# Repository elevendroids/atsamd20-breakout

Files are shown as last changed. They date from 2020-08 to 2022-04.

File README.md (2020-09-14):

# ATSAMD2x (SAM D2x) Breakout Board (Rev. A)

Small breakout board designed for the [SAM D20](http://ww1.microchip.com/downloads/en/DeviceDoc/SAM_D20_%20Family_Datasheet_DS60001504C.pdf) and [SAM D21](http://ww1.microchip.com/downloads/en/DeviceDoc/SAM_D21_DA1_Family_DataSheet_DS40001882F.pdf) ARM Cortex-M0+ microcontrollers from Microchip

## Features

- minimal subset of components, no power regulation etc.
- optional external main and real-time crystals - if not used, their GPIO pins can be connected to the user header by soldering relevant 0R resistors (see schematic)
- one buffered user LED, connected to the header - no reserved GPIO
- reset button
- standard 0.05" pitch SWD programming header, SWD signals also present on the pin headers

Designed in KiCad 5.1.6

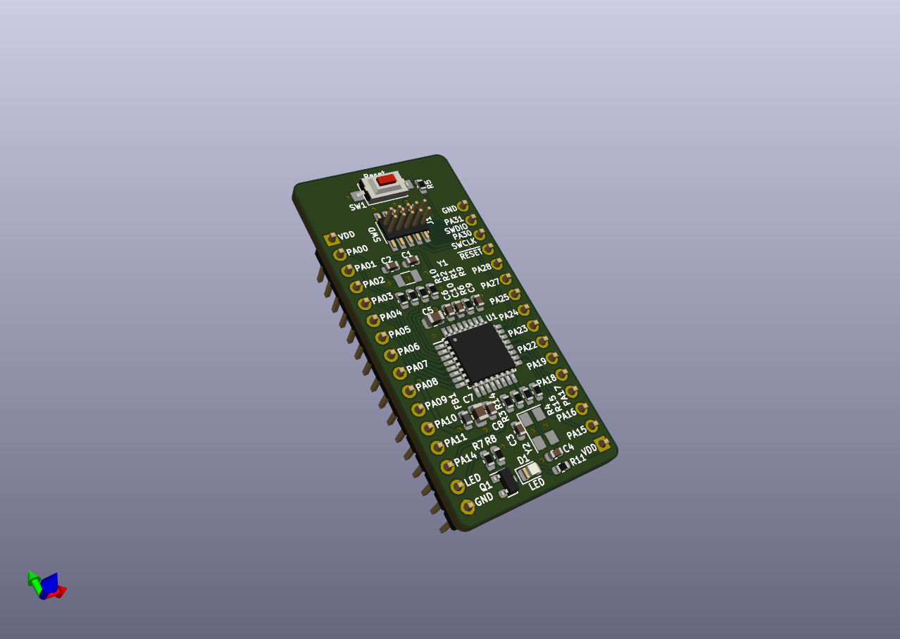
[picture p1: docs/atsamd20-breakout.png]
PCB Render


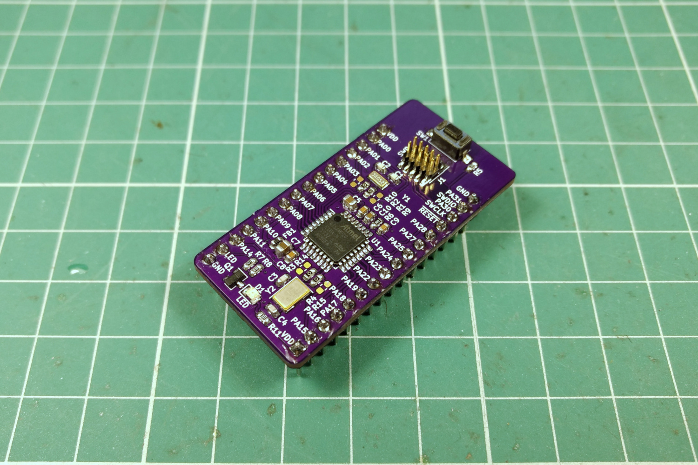
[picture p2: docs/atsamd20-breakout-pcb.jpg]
Prototype


Schematic: [PDF](docs/atsamd20-breakout.pdf)

License: [CC BY-SA 4.0](https://creativecommons.org/licenses/by-sa/4.0/)

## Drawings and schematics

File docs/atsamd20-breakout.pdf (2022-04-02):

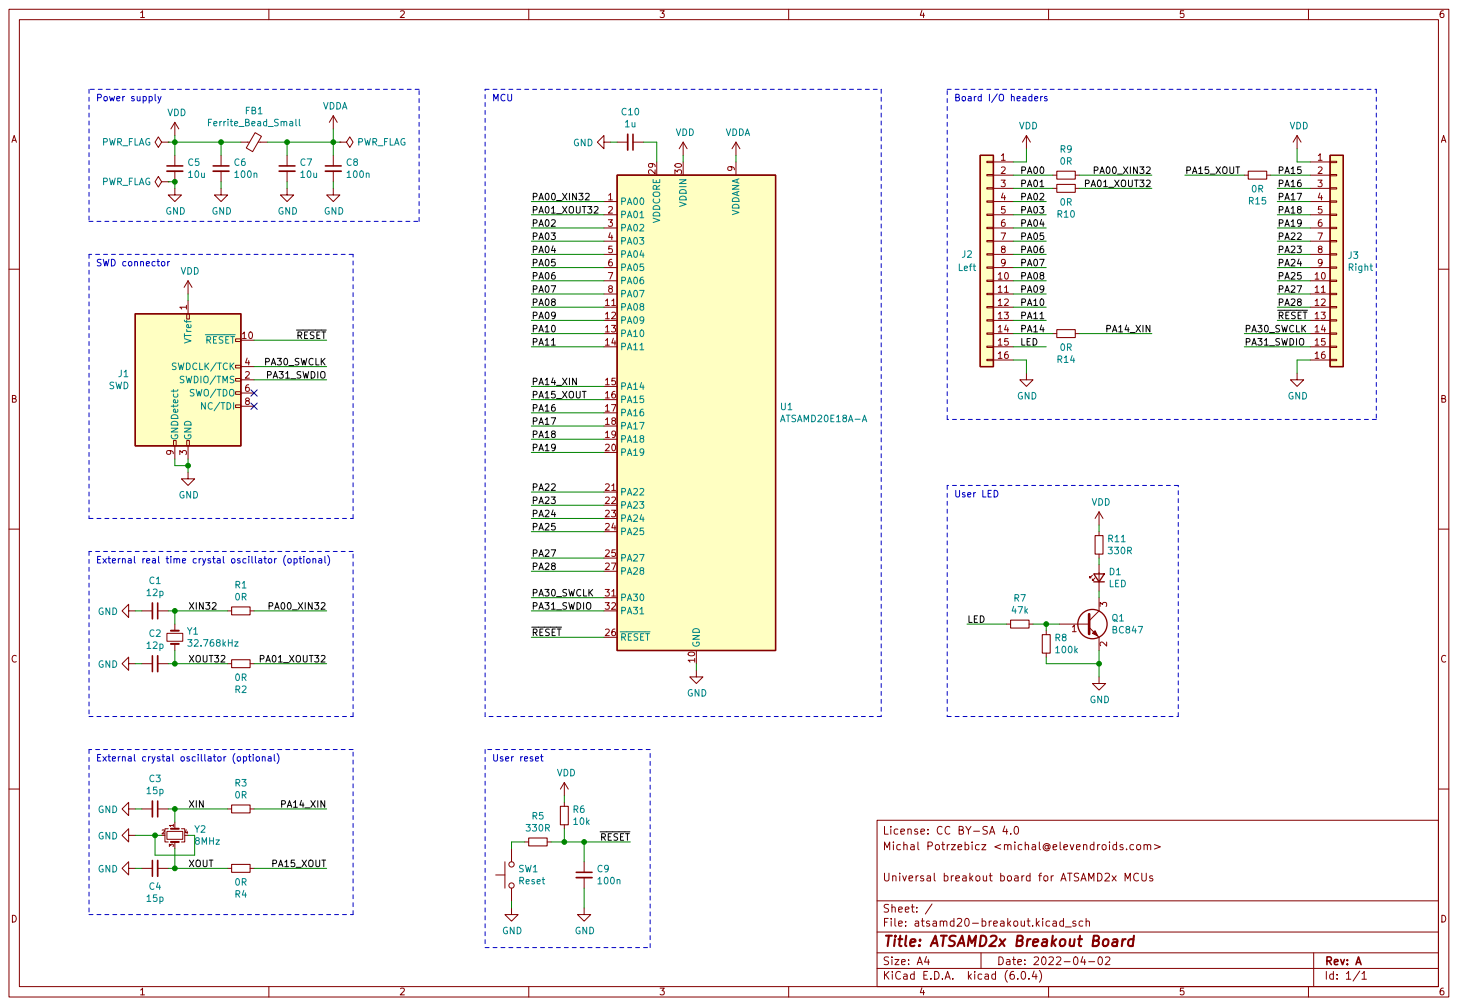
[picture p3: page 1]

3 SWDCLK/TCK 4 SWO/TDO 6 NC/TDI 8 GNDDetect 9

External real time crystal oscillator (optional)
8MHz C1

License: CC BY-SA 4.0
File: atsamd20-breakout.kicad_sch Sheet: / Universal breakout board for ATSAMD2x MCUs Michal Potrzebicz <michal@elevendroids.com>

Id: 1/1 Title: ATSAMD2x Breakout Board

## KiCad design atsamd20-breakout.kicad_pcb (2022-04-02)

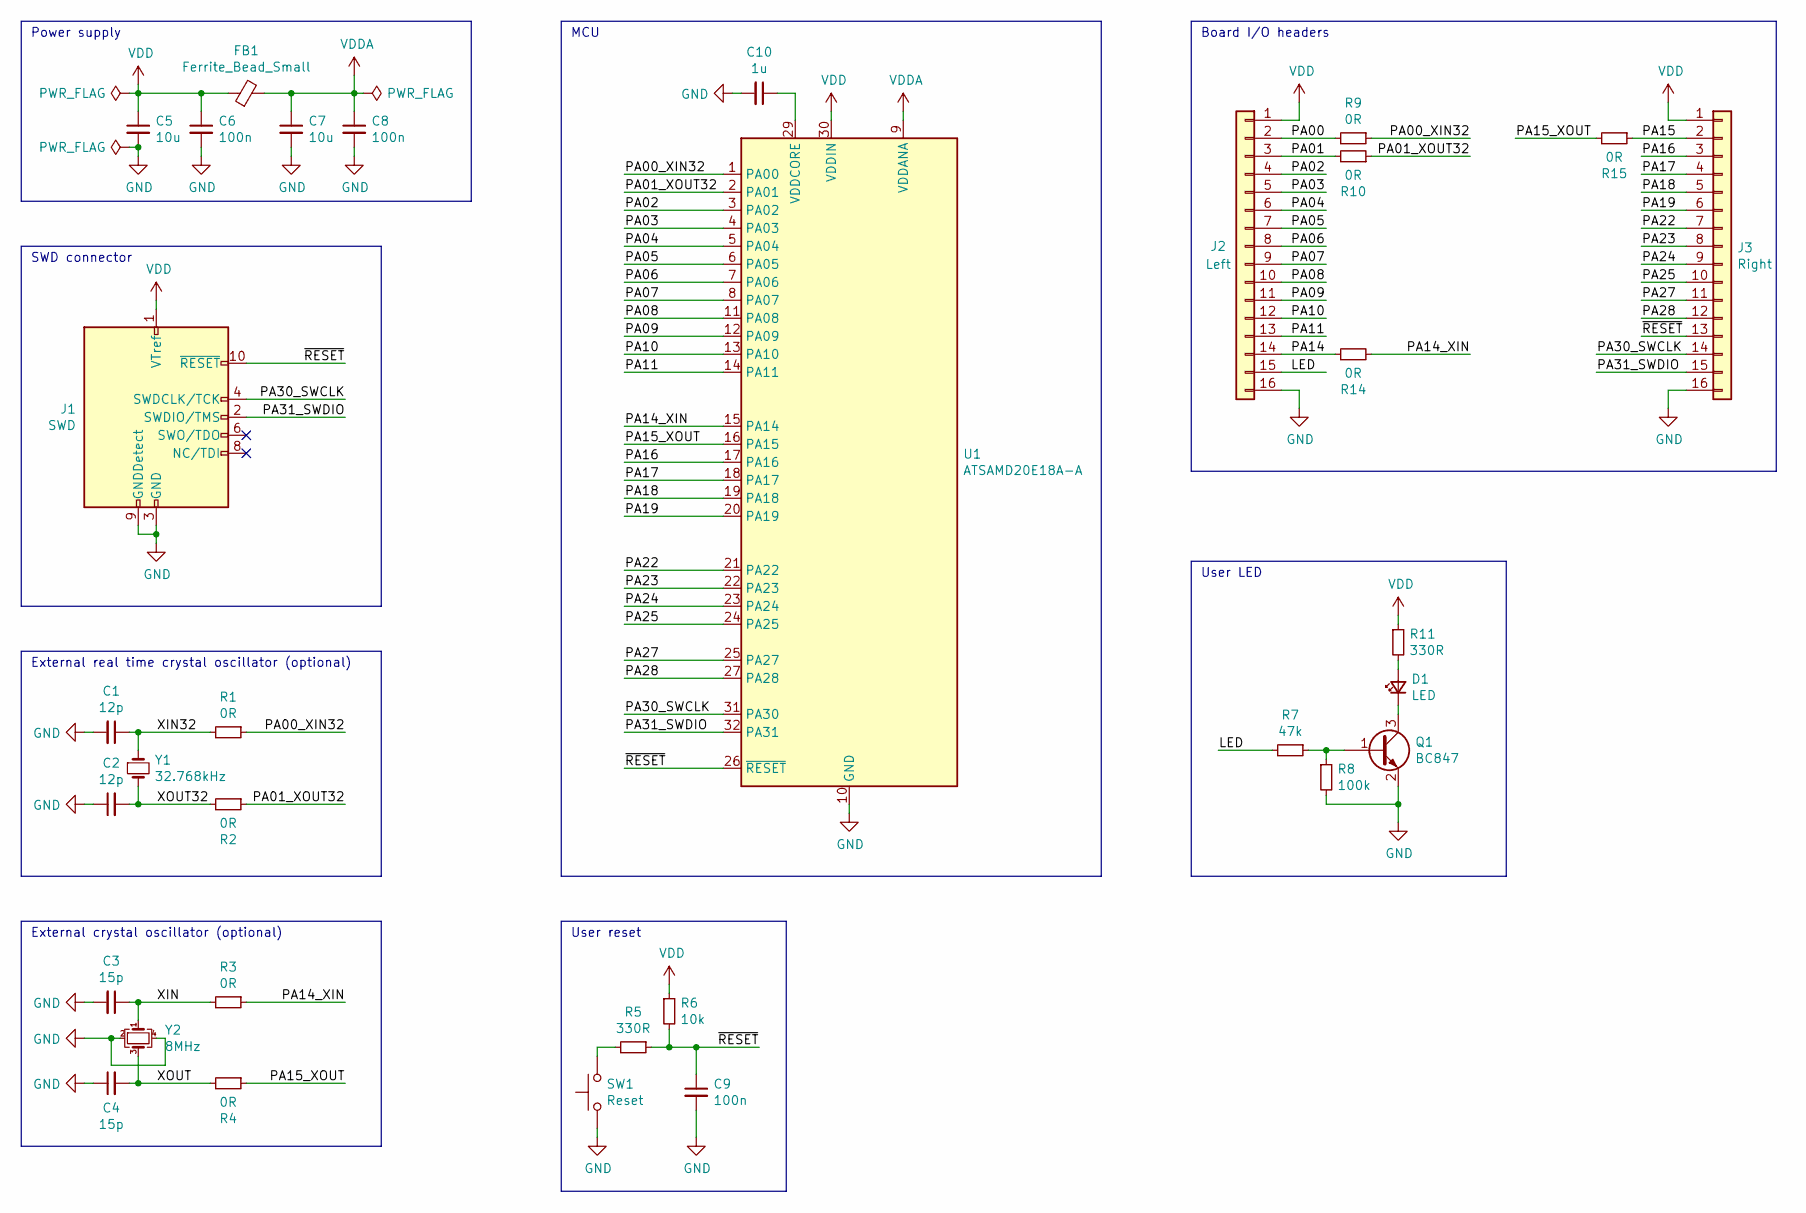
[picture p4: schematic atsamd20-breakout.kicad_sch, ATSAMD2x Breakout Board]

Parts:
C1, C2: 12p; C_0603_1608Metric
C3, C4: 15p; C_0603_1608Metric
C5, C7: 10u; C_0805_2012Metric
C6, C8, C9: 100n; C_0603_1608Metric
C10: 1u; C_0603_1608Metric
D1: LED; LED_0805_2012Metric
FB1: Ferrite_Bead_Small; L_0603_1608Metric
J1: SWD; PinHeader_2x05_P1.27mm_Vertical_SMD
J2: Left; PinHeader_1x16_P2.54mm_Vertical
J3: Right; PinHeader_1x16_P2.54mm_Vertical
Q1: BC847; SOT-23
R1, R2, R3, R4, R9, R10, R14, R15: 0R; R_0603_1608Metric
R5, R11: 330R; R_0603_1608Metric
R6: 10k; R_0603_1608Metric
R7: 47k; R_0603_1608Metric
R8: 100k; R_0603_1608Metric
SW1: Reset; SW_SPST_CK_RS282G05A3
U1: ATSAMD20E18A-A; TQFP-32_7x7mm_P0.8mm
Y1: 32.768kHz; Crystal_SMD_3215-2Pin_3.2x1.5mm
Y2: 8MHz; Crystal_SMD_5032-4Pin_5.0x3.2mm

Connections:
/LED: J2.15, R7.2
/PA00: J2.2, R9.2
/PA00_XIN32: R1.1, R9.1, U1.1 (PA00)
/PA01: J2.3, R10.2
/PA01_XOUT32: R2.1, R10.1, U1.2 (PA01)
/PA02: J2.4, U1.3 (PA02)
/PA03: J2.5, U1.4 (PA03)
/PA04: J2.6, U1.5 (PA04)
/PA05: J2.7, U1.6 (PA05)
/PA06: J2.8, U1.7 (PA06)
/PA07: J2.9, U1.8 (PA07)
/PA08: J2.10, U1.11 (PA08)
/PA09: J2.11, U1.12 (PA09)
/PA10: J2.12, U1.13 (PA10)
/PA11: J2.13, U1.14 (PA11)
/PA14: J2.14, R14.1
/PA14_XIN: R3.1, R14.2, U1.15 (PA14)
/PA15: J3.2, R15.1
/PA15_XOUT: R4.1, R15.2, U1.16 (PA15)
/PA16: J3.3, U1.17 (PA16)
/PA17: J3.4, U1.18 (PA17)
/PA18: J3.5, U1.19 (PA18)
/PA19: J3.6, U1.20 (PA19)
/PA22: J3.7, U1.21 (PA22)
/PA23: J3.8, U1.22 (PA23)
/PA24: J3.9, U1.23 (PA24)
/PA25: J3.10, U1.24 (PA25)
/PA27: J3.11, U1.25 (PA27)
/PA28: J3.12, U1.27 (PA28)
/PA30_SWCLK: J1.4 (SWDCLK/TCK), J3.14, U1.31 (PA30)
/PA31_SWDIO: J1.2 (SWDIO/TMS), J3.15, U1.32 (PA31)
/XIN: C3.1, R3.2, Y2.1
/XIN32: C1.1, R1.2, Y1.1
/XOUT: C4.2, R4.2, Y2.3
/XOUT32: C2.2, R2.2, Y1.2
/~RESET: C9.1, J1.10 (~RESET), J3.13, R5.1, R6.2, U1.26 (~RESET)
GND: C1.2, C2.1, C3.2, C4.1, C5.2, C6.2, C7.2, C8.2, C9.2, C10.2, J1.3 (GND), J1.5 (GND), J1.9 (GNDDetect), J2.16, J3.16, Q1.2 (E), R8.2, SW1.1, U1.10 (GND), U1.28 (GND), Y2.2, Y2.4
unnamed: C10.1, U1.29 (VDDCORE)
unnamed: D1.1 (K), Q1.3 (C)
unnamed: D1.2 (A), R11.2
unnamed: Q1.1 (B), R7.1, R8.1
unnamed: R5.2, SW1.2
VDD: C5.1, C6.1, FB1.1, J1.1 (VTref), J2.1, J3.1, R6.1, R11.1, U1.30 (VDDIN)
VDDA: C7.1, C8.1, FB1.2, U1.9 (VDDANA)

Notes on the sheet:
SWD connector
User reset
External crystal oscillator (optional)
External real time crystal oscillator (optional)
Board I/O headers
MCU
User LED
Power supply

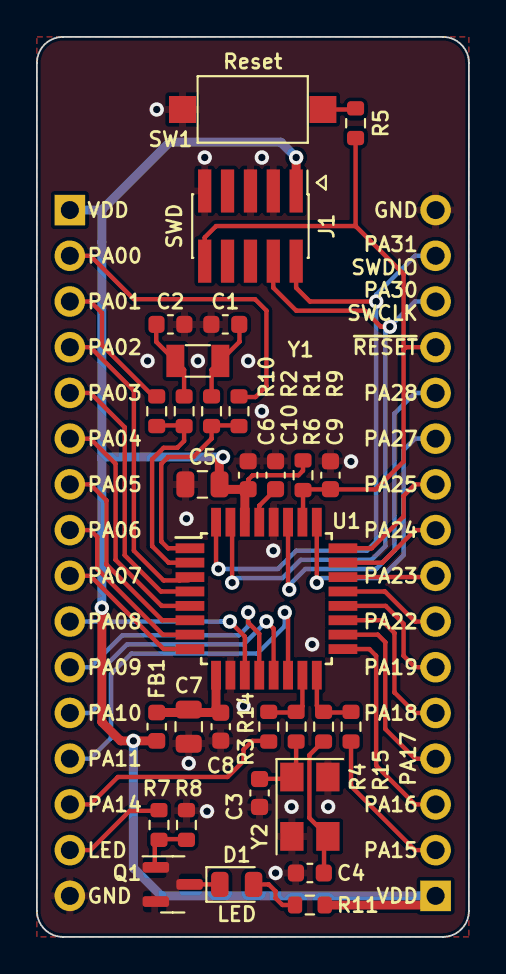
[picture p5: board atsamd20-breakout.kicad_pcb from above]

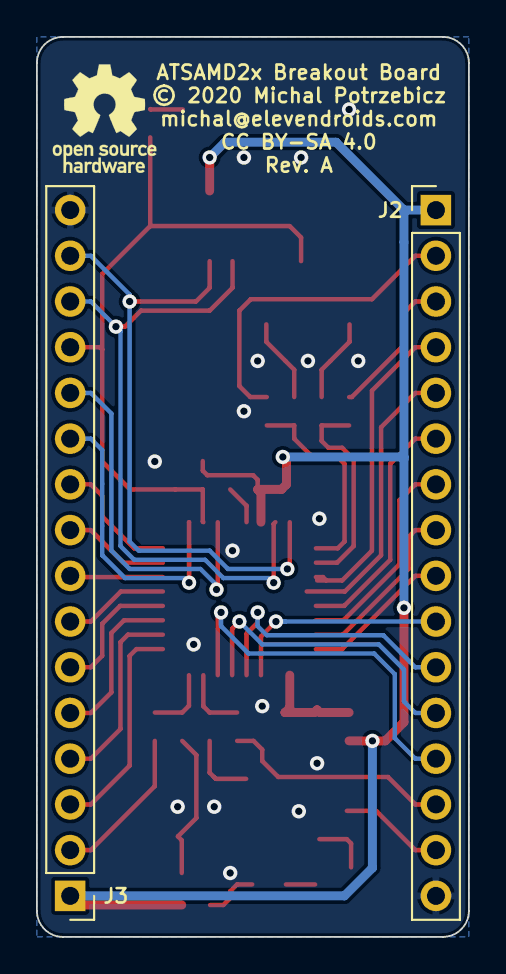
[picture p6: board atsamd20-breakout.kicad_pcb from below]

Board: 2 copper layers, 24.0 x 50.0 mm, 33 parts (2 on the bottom side), 44 nets.

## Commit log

2020-08-02 Initial commit, schematic completed
    [atsamd20-breakout.kicad_pcb, atsamd20-breakout.sch]
2020-08-02 Replaced LED1 pin with RESET, removed LED1 circuit
    [atsamd20-breakout.sch]
2020-08-02 Fixed net names
    [atsamd20-breakout.sch]
2020-08-03 Fixed SWD connector wire labels
    [atsamd20-breakout.sch]
2020-08-16 Finished (hopefully) the layout for the Rev. A
    [atsamd20-breakout.kicad_pcb, atsamd20-breakout.sch]
2020-08-17 Added readme, license and pcb render
2020-08-29 Added pin 1 indicator for the SWD connector
    [atsamd20-breakout.kicad_pcb]
2020-09-14 Added photo of the first prototype from OSHPark
2020-09-14 Added interactive BOM
2022-04-02 Project upgrade to KiCad 6
    [atsamd20-breakout.kicad_pcb, atsamd20-breakout.kicad_sch, atsamd20-breakout.sch]

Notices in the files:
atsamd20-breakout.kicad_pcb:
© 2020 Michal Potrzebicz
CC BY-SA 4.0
